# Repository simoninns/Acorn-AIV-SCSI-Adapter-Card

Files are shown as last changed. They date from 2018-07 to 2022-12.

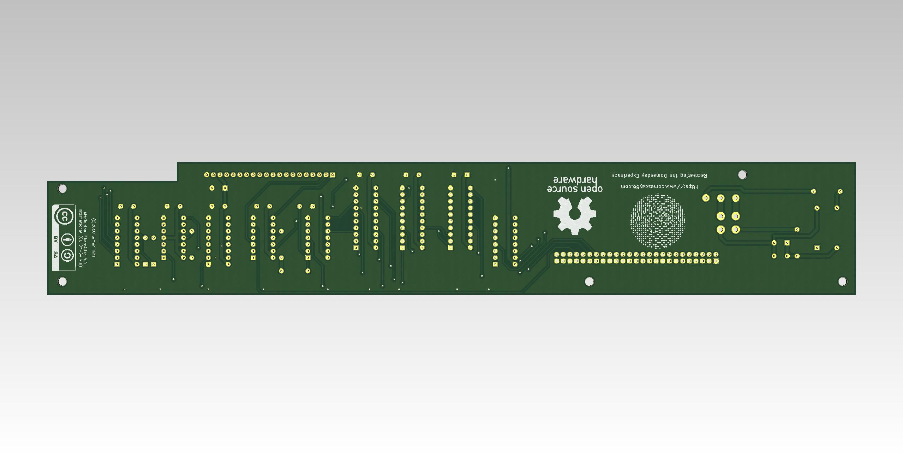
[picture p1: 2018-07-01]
Acorn AIV SCSI Adapter - Bottom.jpg

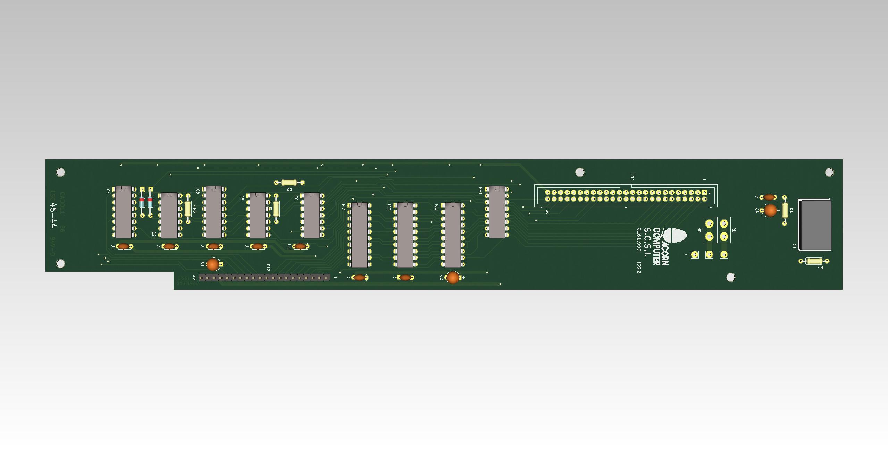
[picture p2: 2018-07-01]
Acorn AIV SCSI Adapter - Top.jpg

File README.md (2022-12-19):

# Acorn-AIV-SCSI-Adapter-Card
A reproduction of the original Acorn AIV SCSI Adapter Card in KiCAD (as used in the BBC Domesday System)

For more information please see the [project wiki pages](https://github.com/simoninns/Acorn-AIV-SCSI-Adapter-Card/wiki)

## Synopsis

This card is designed as a drop-in replacement for the original Acorn card in the BBC Master Microcomputer and allows connection of SCSI devices (such as the Philips VP415 Domesday LaserDisc player).

The layout and routing of the board is based on the original and the board is therefore designed to use the same components.

## Motivation

The Acorn AIV SCSI board is difficult to source and commands a considerable sum on sites such as Ebay.  Using this project you are free to create your own boards for far less cost.  The design and schematics also act as a precise reference to the original design.  The original schematics are available on the web, however they are incorrect.  By recreating the board and following the original routing, the schematics included in this project are verified as correct.

## Author

The Acorn AIV SCSI Adapter Card issue 2 was designed by Simon Inns.

## License

This project is released under a Creative Commons Attribution-ShareAlike 4.0 International (CC BY-SA 4.0) licence.

You are free to:

Share — copy and redistribute the material in any medium or format
Adapt — remix, transform, and build upon the material
for any purpose, even commercially.

This license is acceptable for Free Cultural Works.

The licensor cannot revoke these freedoms as long as you follow the license terms.

Under the following terms:

Attribution — You must give appropriate credit, provide a link to the license,
and indicate if changes were made. You may do so in any reasonable manner, but
not in any way that suggests the licensor endorses you or your use.

ShareAlike — If you remix, transform, or build upon the material, you must
distribute your contributions under the same license as the original.

No additional restrictions — You may not apply legal terms or technological
measures that legally restrict others from doing anything the license permits.

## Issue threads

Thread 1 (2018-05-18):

Mounting holes too small

simoninns, 2018-05-18:
The mounting holes in the current board revision are 2mm in diameter.  The mounting holes should be 3mm.

simoninns, 2018-05-27:
Fixed in latest commit - Mounting holes now M3

Closed 2018-05-27.

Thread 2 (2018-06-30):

Mounting holes not correctly lined up

simoninns, 2018-06-30:
The top mounting holes are a little out (<1mm), but the bottom mounting holes are 2mm out.

The holes need to be checked for alignment between the holes and also with the board in place to make sure the board isn't offset

simoninns, 2018-07-01:
Fixed in commit 3297891

Closed 2018-07-01.

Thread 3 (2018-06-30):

No 16Mhz clock

simoninns, 2018-06-30:
The board doesn't seem to be generating the 16MHz clock signal correctly.  This needs to be checked.

simoninns, 2018-07-01:
This seems to be due to incorrect part selection.  The pin out and routing of the board verifies ok, but the selected component does not produce the required 5V TTL clock output

simoninns, 2018-07-01:
This was due to an incorrect resistor value on the test board.  Clock circuit now verified ok in commit 3297891

Closed 2018-07-01.

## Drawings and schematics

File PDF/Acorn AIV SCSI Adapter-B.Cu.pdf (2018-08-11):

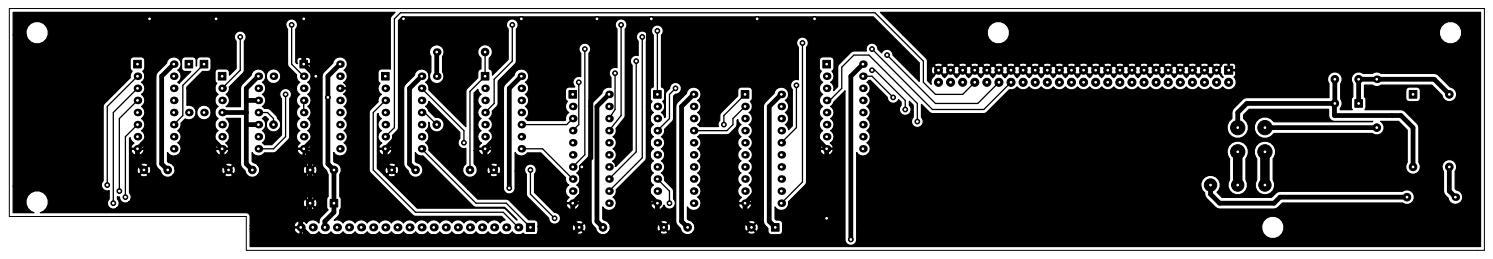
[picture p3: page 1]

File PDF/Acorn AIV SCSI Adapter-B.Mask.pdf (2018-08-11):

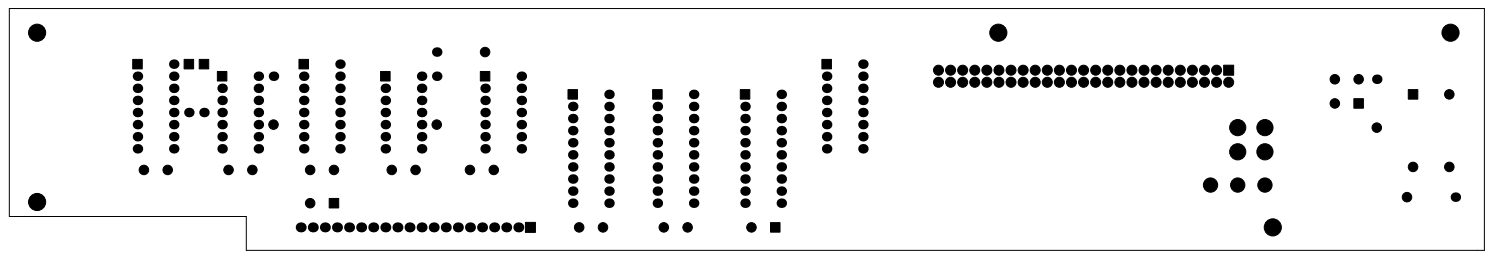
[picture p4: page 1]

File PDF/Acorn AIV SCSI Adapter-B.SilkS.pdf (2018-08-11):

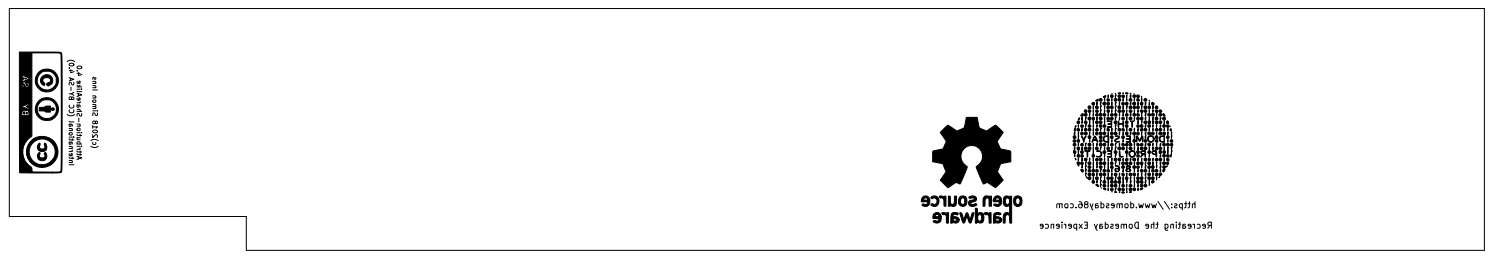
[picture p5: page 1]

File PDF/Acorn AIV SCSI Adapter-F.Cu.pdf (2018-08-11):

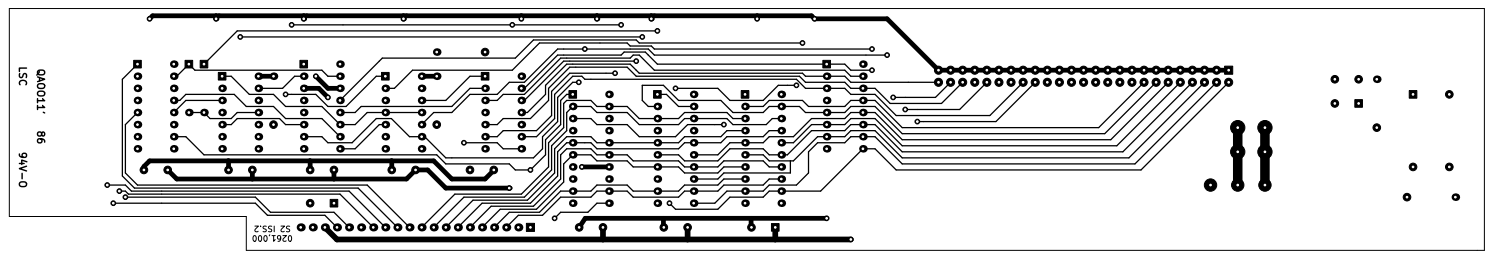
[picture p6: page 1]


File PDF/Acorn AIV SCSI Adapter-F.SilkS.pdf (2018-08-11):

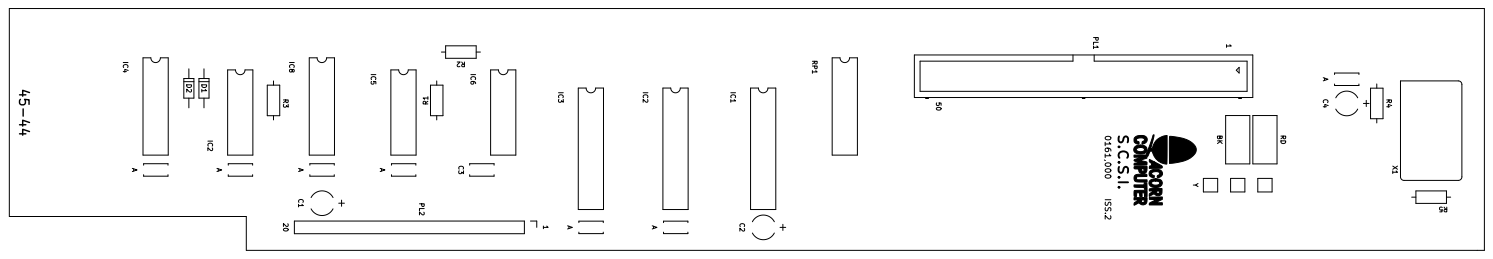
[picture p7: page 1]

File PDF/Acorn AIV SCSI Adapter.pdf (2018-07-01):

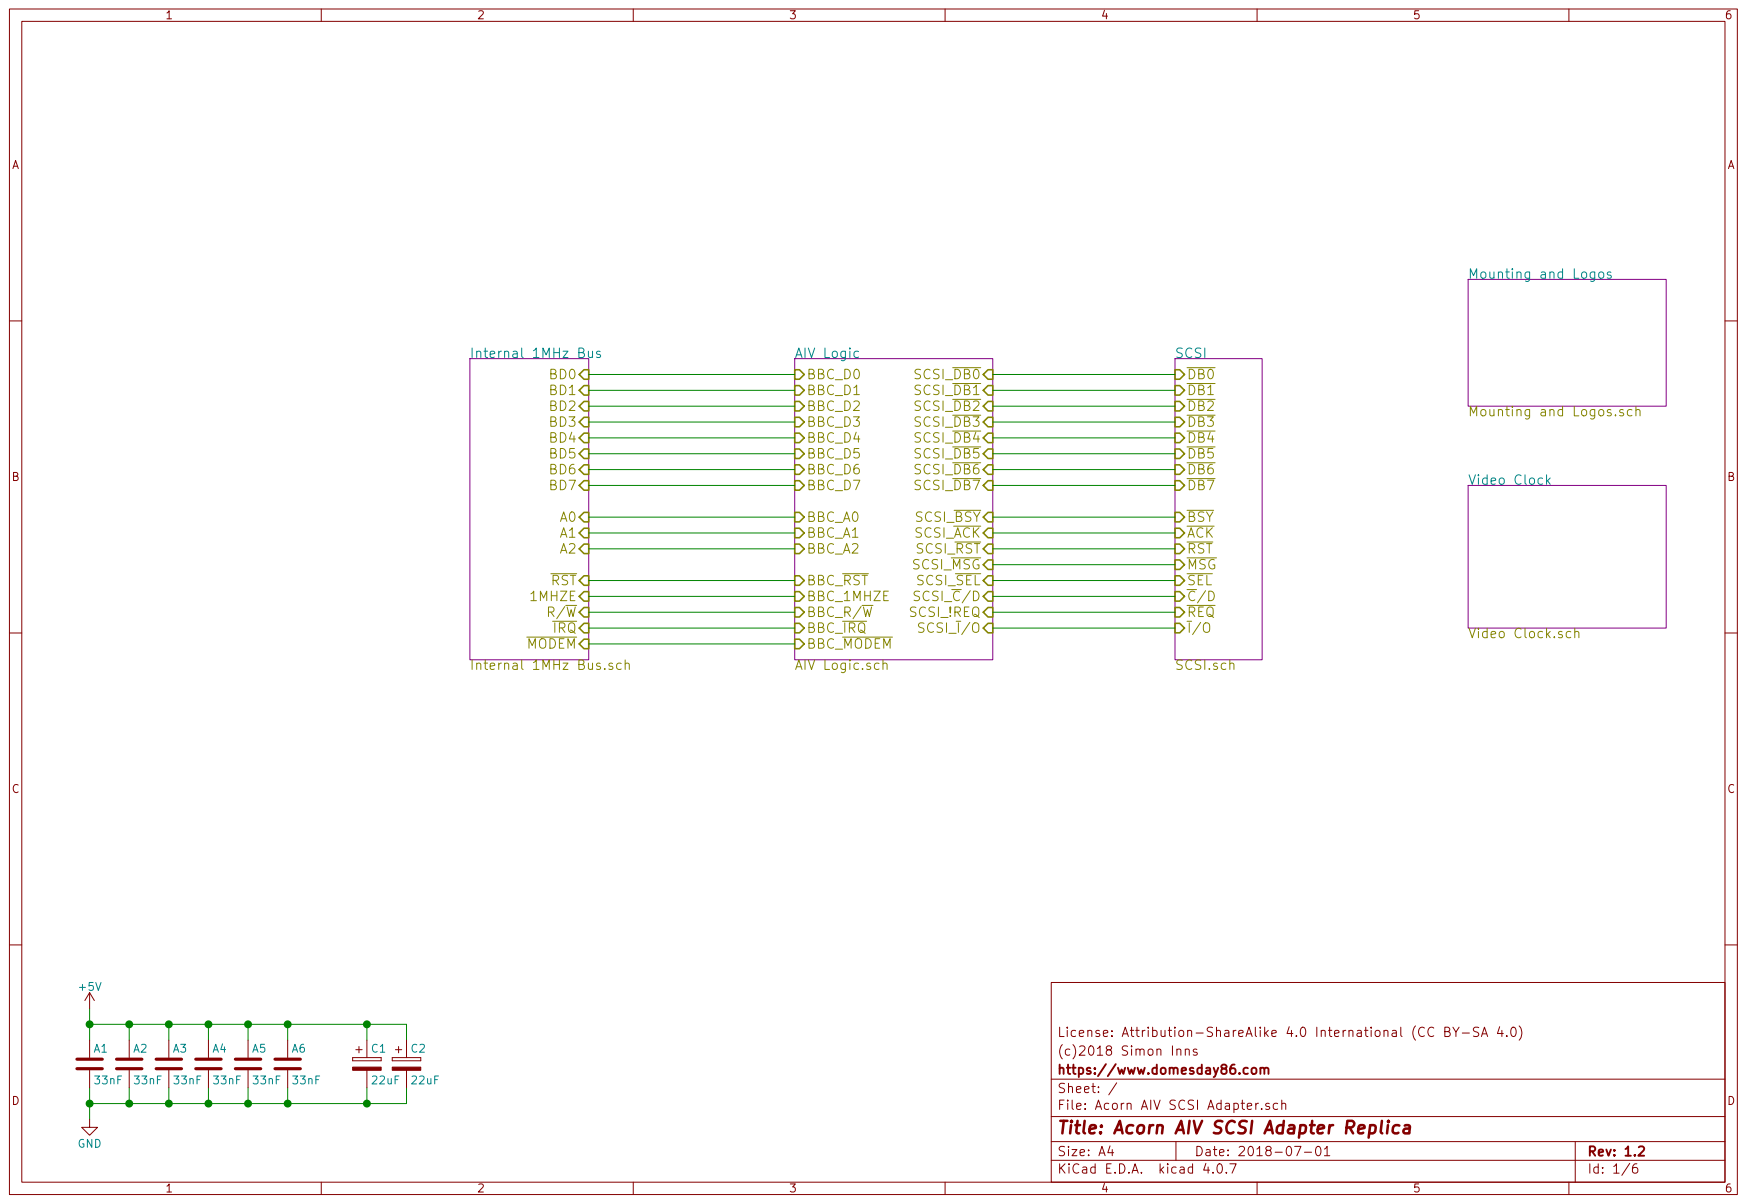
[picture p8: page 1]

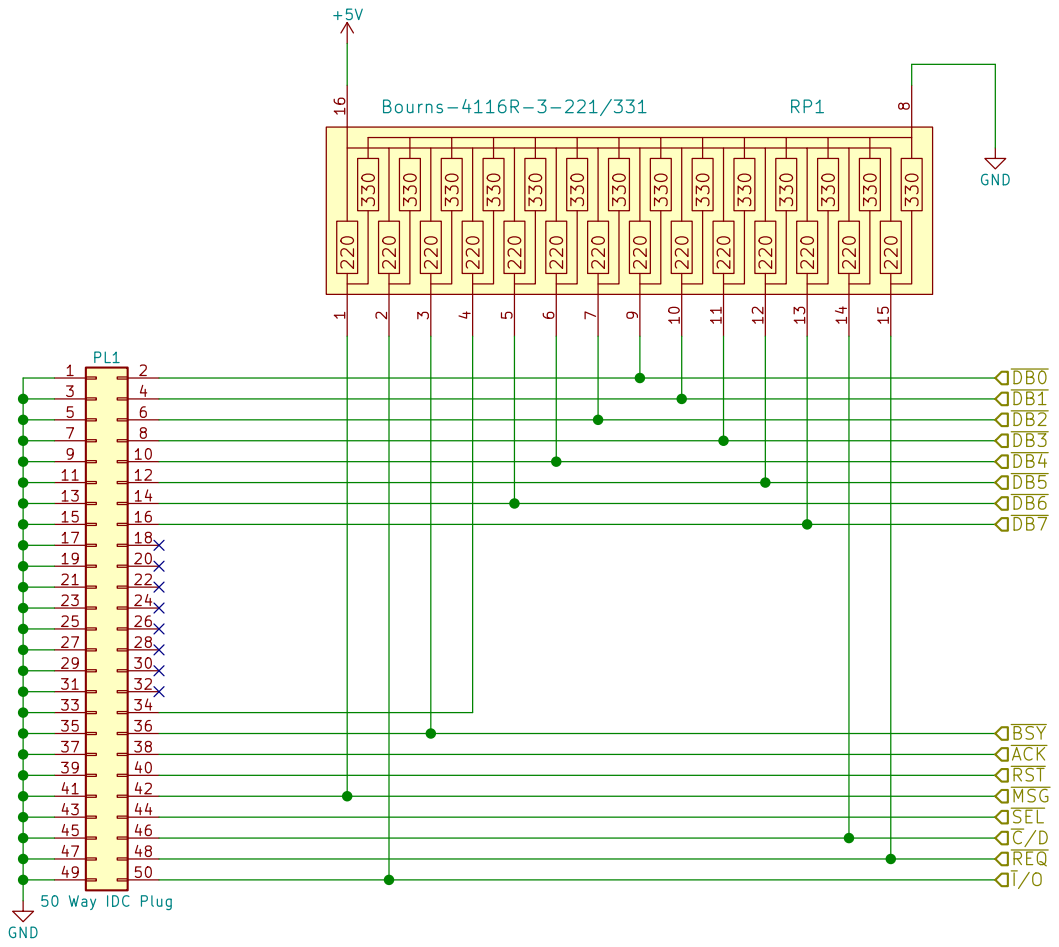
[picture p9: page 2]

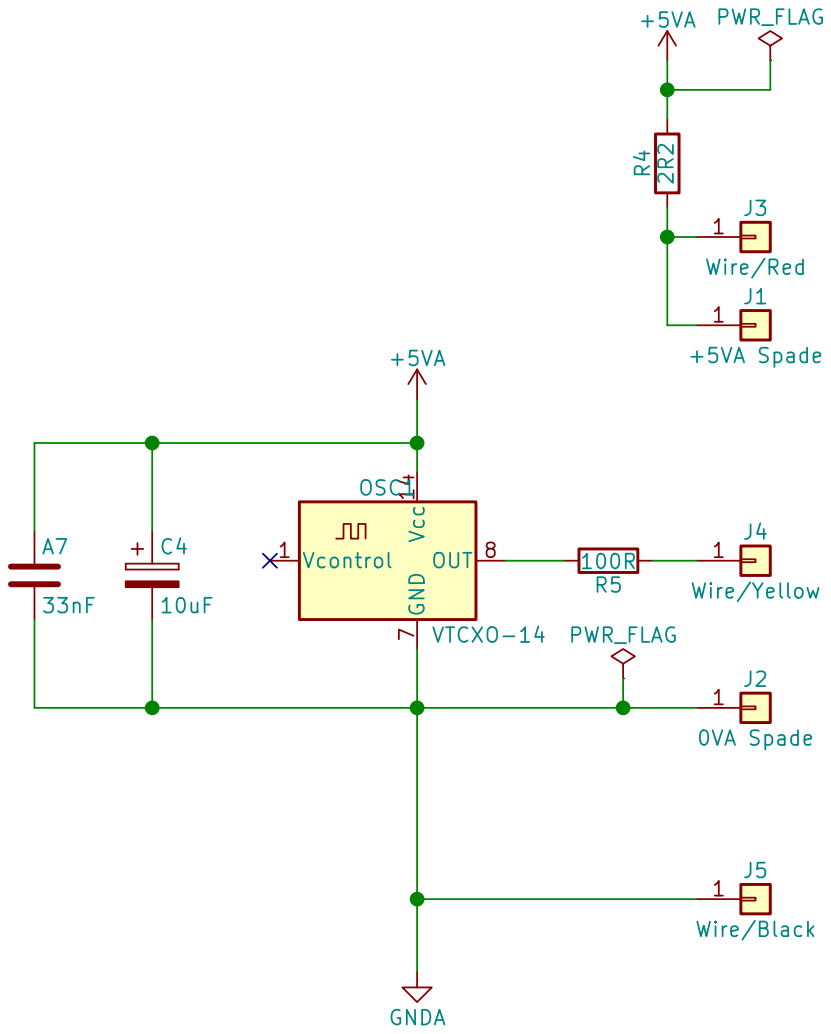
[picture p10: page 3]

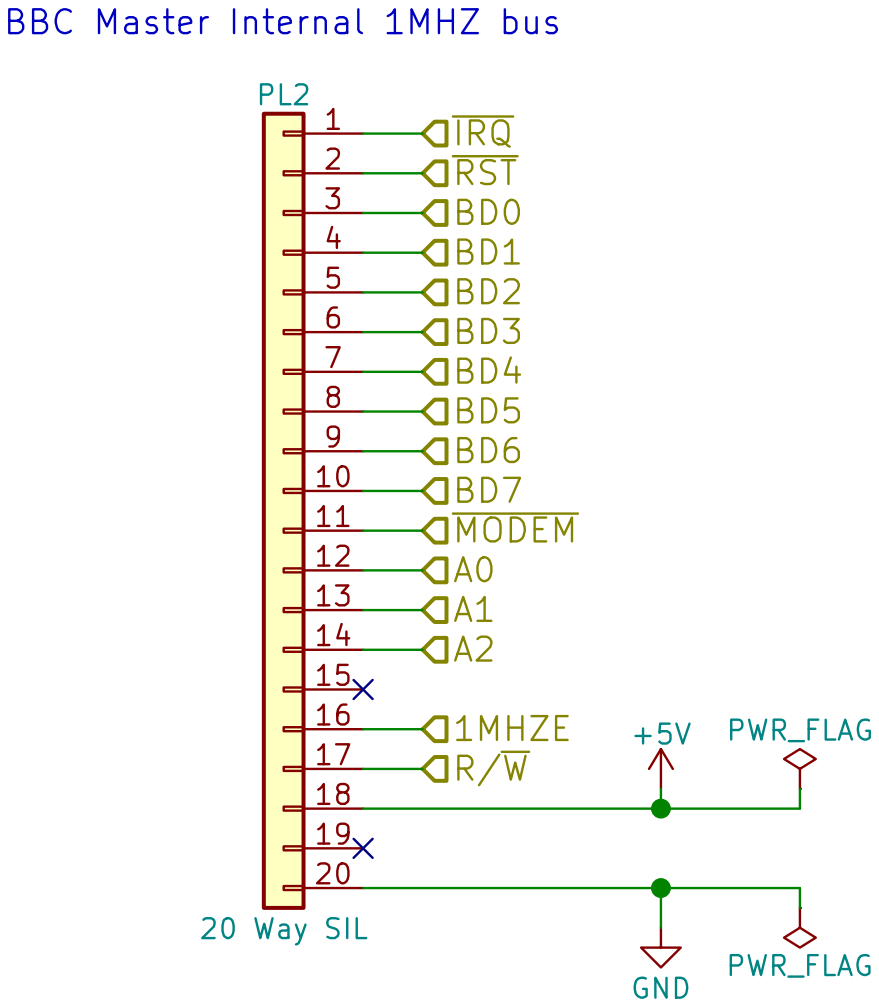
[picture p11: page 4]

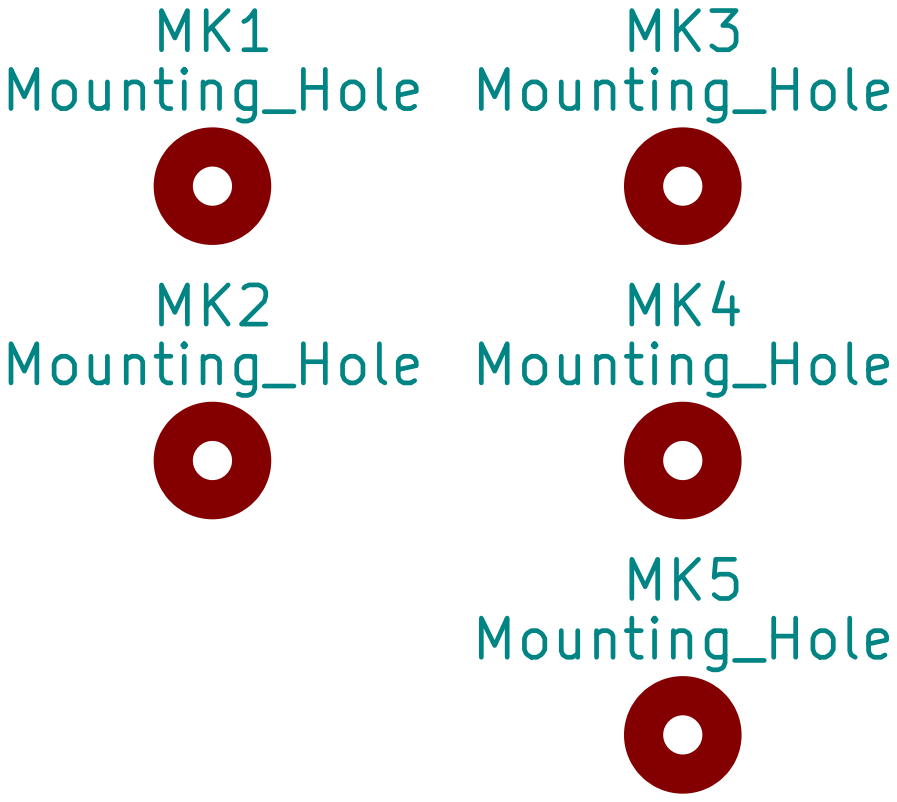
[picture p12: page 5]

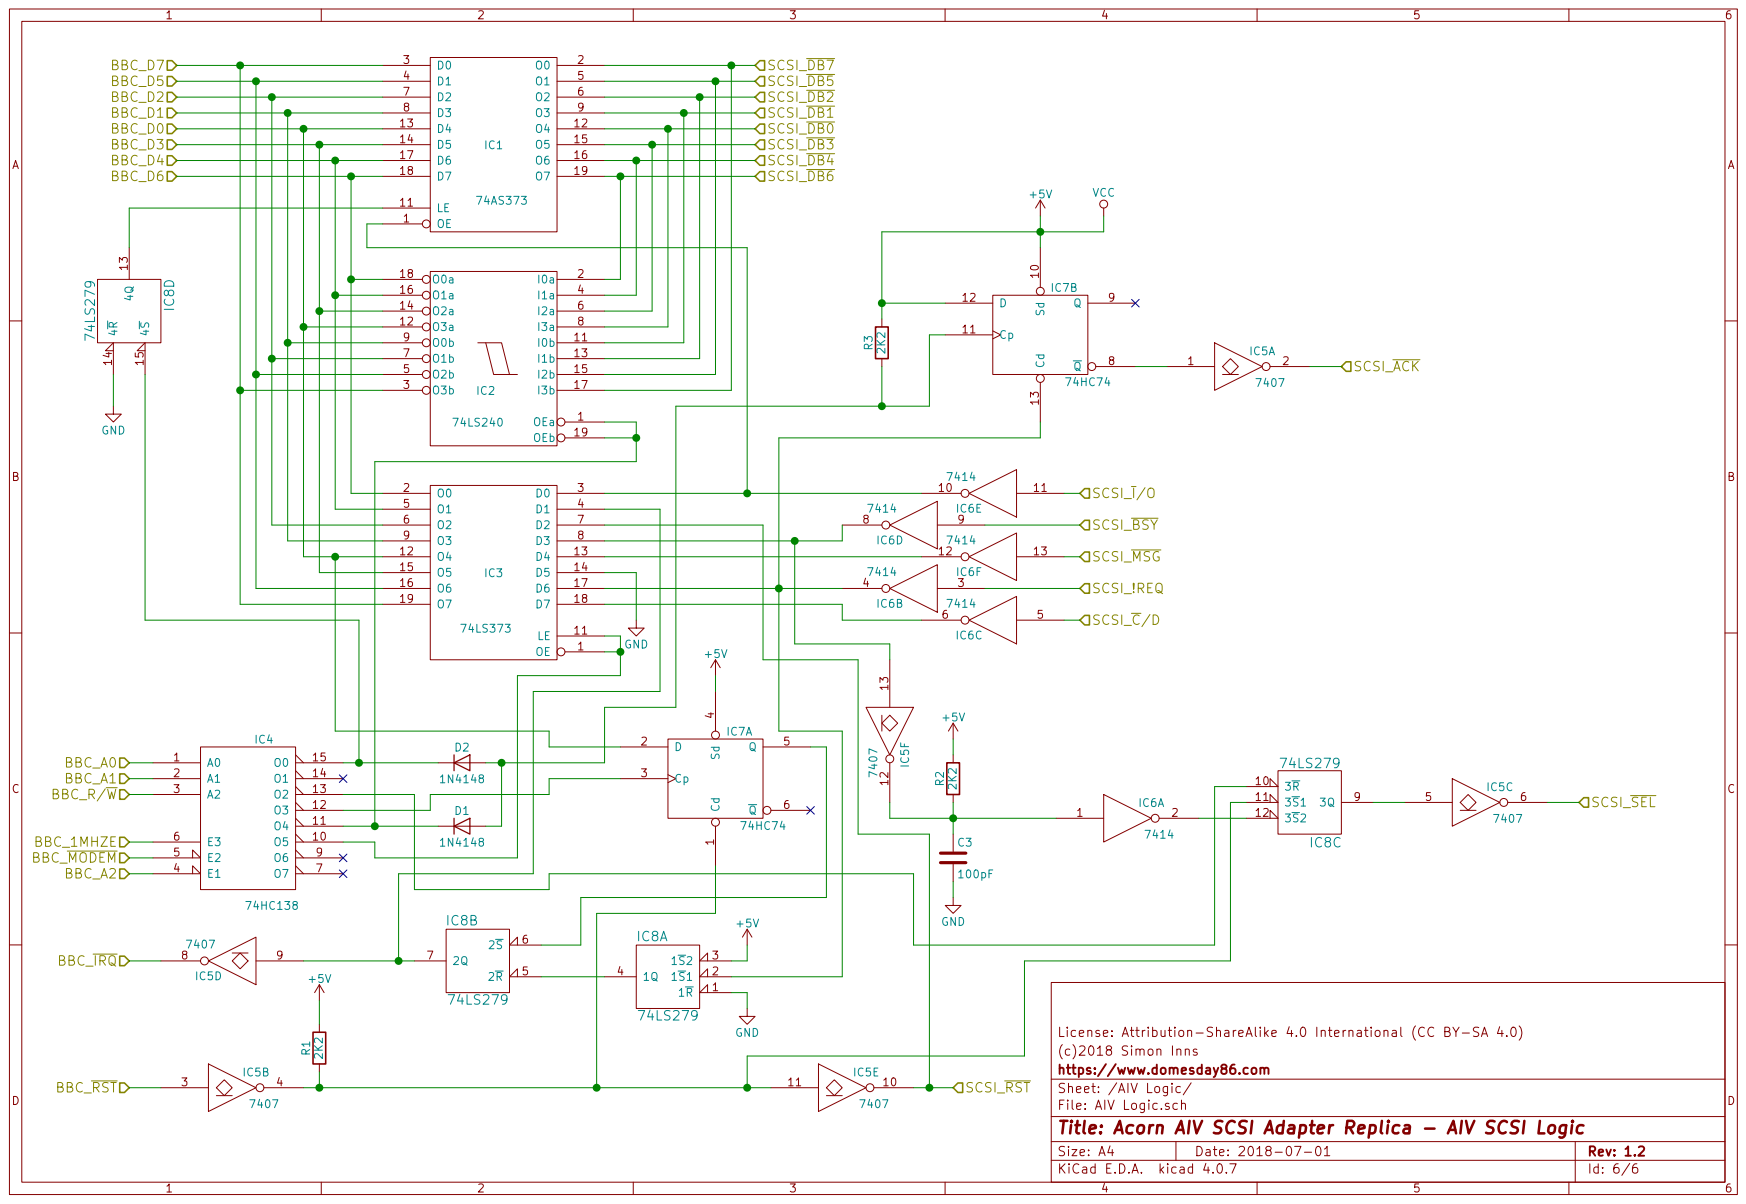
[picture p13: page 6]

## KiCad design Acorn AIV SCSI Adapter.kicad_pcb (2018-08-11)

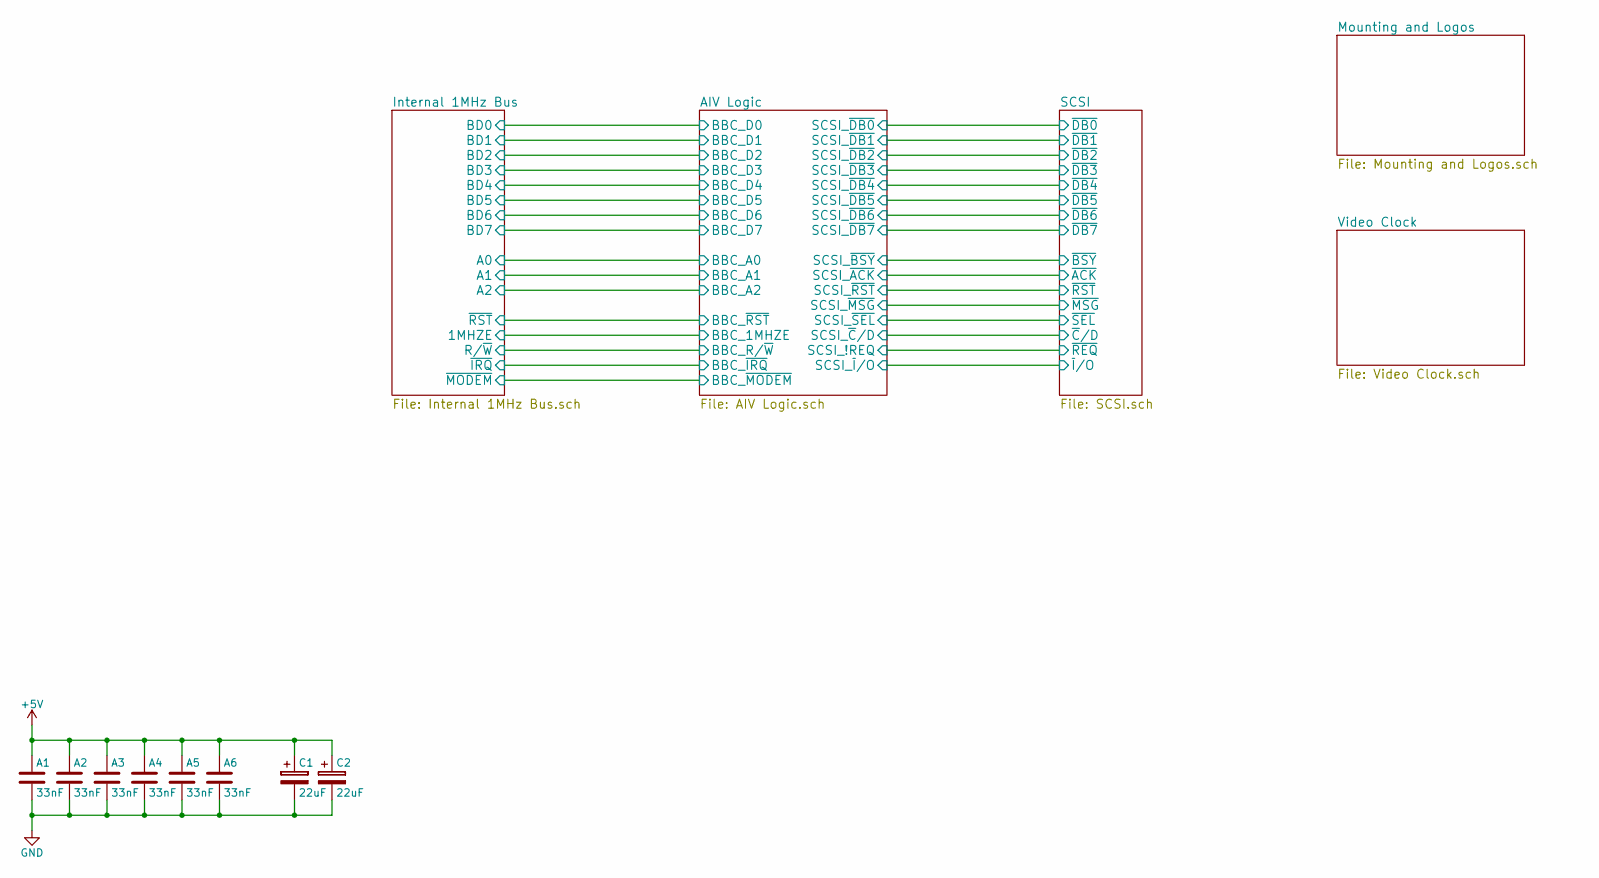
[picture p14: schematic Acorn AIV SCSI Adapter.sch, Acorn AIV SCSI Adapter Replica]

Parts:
A1, A2, A3, A4, A5, A6: 33nF; C_Disc_D5.0mm_W2.5mm_P5.00mm
C1, C2: 22uF; CP_Radial_Tantal_D5.0mm_P5.00mm

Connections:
+5V: A1.1, A2.1, A3.1, A4.1, A5.1, A6.1, C1.1, C2.1; also elsewhere on the board
GND: A1.2, A2.2, A3.2, A4.2, A5.2, A6.2, C1.2, C2.2; also elsewhere on the board

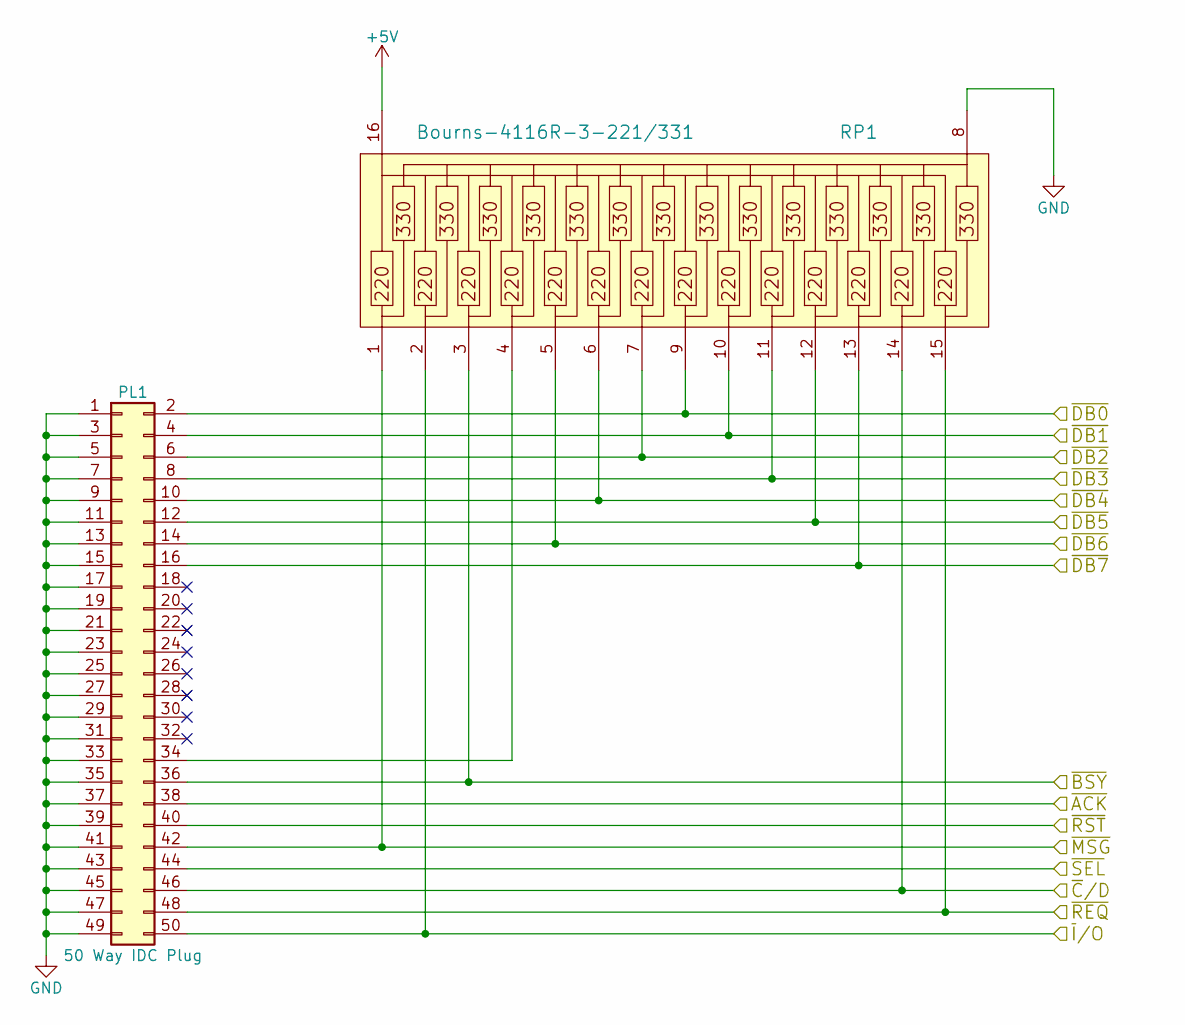
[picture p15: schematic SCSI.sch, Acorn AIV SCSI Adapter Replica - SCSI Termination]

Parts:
PL1: 50 Way IDC Plug; Multicomp_MC9A12-5034_2x25x2.54mm_Straight
RP1: Bourns-4116R-3-221/331; DIP-16_W7.62mm

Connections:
+5V: RP1.16; also elsewhere on the board
/AIV Logic/SCSI_!REQ: PL1.48, RP1.15; also elsewhere on the board
/AIV Logic/SCSI_~ACK: PL1.38; also elsewhere on the board
/AIV Logic/SCSI_~BSY: PL1.36, RP1.3; also elsewhere on the board
/AIV Logic/SCSI_~C~/D: PL1.46, RP1.14; also elsewhere on the board
/AIV Logic/SCSI_~DB0: PL1.2, RP1.9; also elsewhere on the board
/AIV Logic/SCSI_~DB1: PL1.4, RP1.10; also elsewhere on the board
/AIV Logic/SCSI_~DB2: PL1.6, RP1.7; also elsewhere on the board
/AIV Logic/SCSI_~DB3: PL1.8, RP1.11; also elsewhere on the board
/AIV Logic/SCSI_~DB4: PL1.10, RP1.6; also elsewhere on the board
/AIV Logic/SCSI_~DB5: PL1.12, RP1.12; also elsewhere on the board
/AIV Logic/SCSI_~DB6: PL1.14, RP1.5; also elsewhere on the board
/AIV Logic/SCSI_~DB7: PL1.16, RP1.13; also elsewhere on the board
/AIV Logic/SCSI_~I~/O: PL1.50, RP1.2; also elsewhere on the board
/AIV Logic/SCSI_~MSG: PL1.42, RP1.1; also elsewhere on the board
/AIV Logic/SCSI_~RST: PL1.40; also elsewhere on the board
/AIV Logic/SCSI_~SEL: PL1.44; also elsewhere on the board
GND: PL1.1, PL1.3, PL1.5, PL1.7, PL1.9, PL1.11, PL1.13, PL1.15, PL1.17, PL1.19, PL1.21, PL1.23, PL1.25, PL1.27, PL1.29, PL1.31, PL1.33, PL1.35, PL1.37, PL1.39, PL1.41, PL1.43, PL1.45, PL1.47, PL1.49, RP1.8; also elsewhere on the board
unnamed: PL1.34, RP1.4

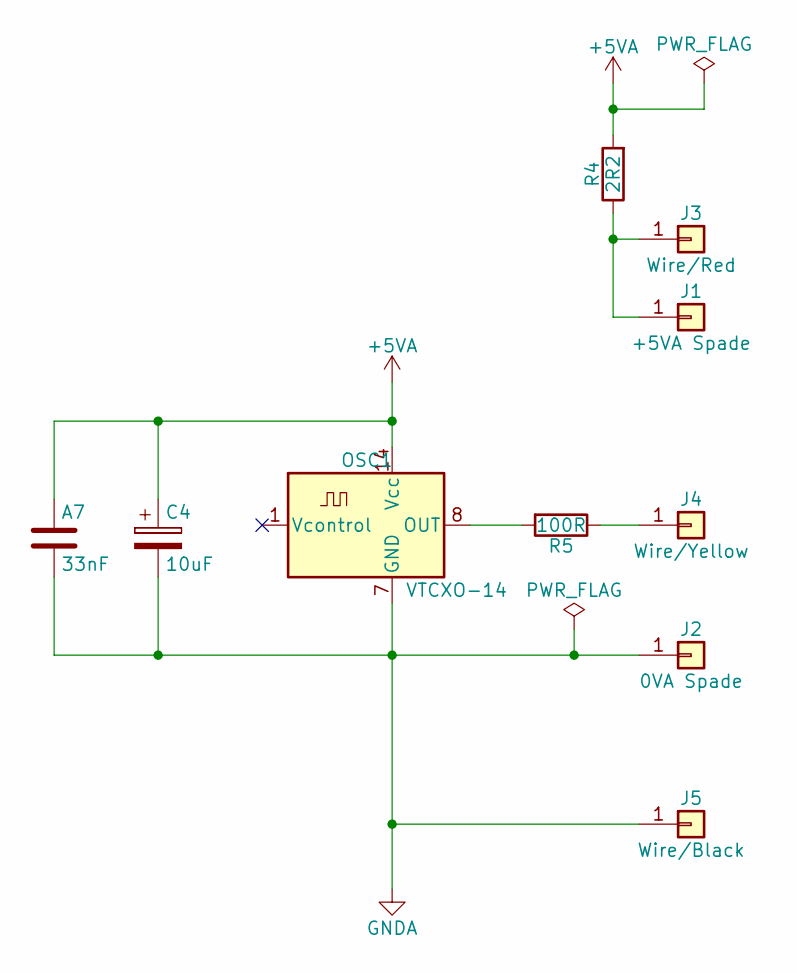
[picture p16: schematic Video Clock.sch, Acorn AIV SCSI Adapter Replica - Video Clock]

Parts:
A7: 33nF; C_Disc_D5.0mm_W2.5mm_P5.00mm
C4: 10uF; CP_Radial_Tantal_D5.0mm_P5.00mm
J1: +5VA Spade; PCB_Blade_Terminal_6.3mm
J2: 0VA Spade; PCB_Blade_Terminal_6.3mm
J3: Wire/Red; Pin_d1.4mm_L8.5mm_W2.8mm_FlatFork
J4: Wire/Yellow; Pin_d1.4mm_L8.5mm_W2.8mm_FlatFork
J5: Wire/Black; Pin_d1.4mm_L8.5mm_W2.8mm_FlatFork
OSC1: VTCXO-14; Oscillator_DIP-14
R4: 2R2; R_Axial_DIN0207_L6.3mm_D2.5mm_P10.16mm_Horizontal
R5: 100R; R_Axial_DIN0207_L6.3mm_D2.5mm_P10.16mm_Horizontal

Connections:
+5VA: A7.1, C4.1, OSC1.14 (Vcc), R4.2
GNDA: A7.2, C4.2, J2.1, J5.1, OSC1.7 (GND)
unnamed: J1.1, J3.1, R4.1
unnamed: J4.1, R5.1
unnamed: OSC1.8 (OUT), R5.2

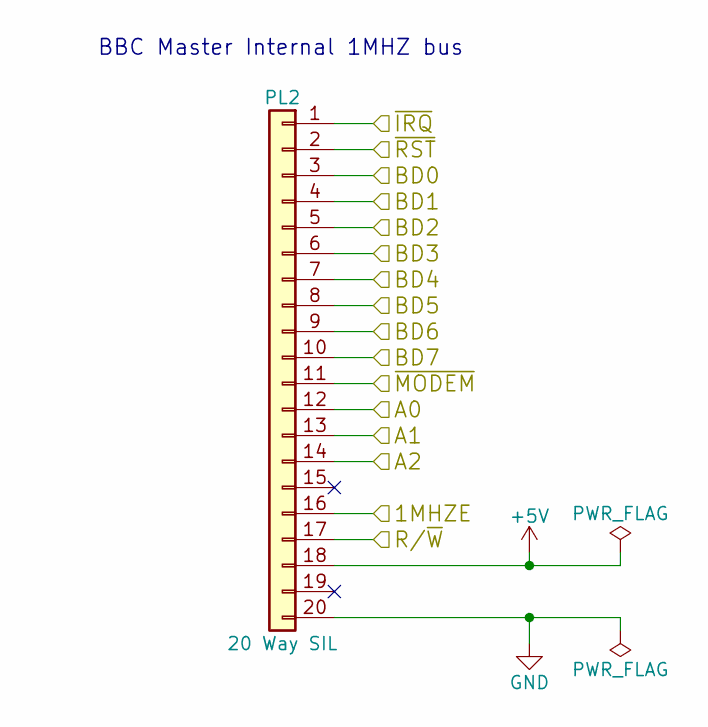
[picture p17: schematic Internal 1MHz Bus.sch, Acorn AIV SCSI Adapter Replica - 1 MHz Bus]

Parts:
PL2: 20 Way SIL; Pin_Header_Straight_1x20_Pitch2.54mm

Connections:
+5V: PL2.18; also elsewhere on the board
/AIV Logic/BBC_D0: PL2.3; also elsewhere on the board
/AIV Logic/BBC_D1: PL2.4; also elsewhere on the board
/AIV Logic/BBC_D2: PL2.5; also elsewhere on the board
/AIV Logic/BBC_D3: PL2.6; also elsewhere on the board
/AIV Logic/BBC_D4: PL2.7; also elsewhere on the board
/AIV Logic/BBC_D5: PL2.8; also elsewhere on the board
/AIV Logic/BBC_D6: PL2.9; also elsewhere on the board
/AIV Logic/BBC_D7: PL2.10; also elsewhere on the board
/AIV Logic/BBC_R/~W: PL2.17; also elsewhere on the board
/AIV Logic/BBC_~IRQ: PL2.1; also elsewhere on the board
/AIV Logic/BBC_~MODEM: PL2.11; also elsewhere on the board
/AIV Logic/BBC_~RST: PL2.2; also elsewhere on the board
/Internal 1MHz Bus/1MHZE: PL2.16; also elsewhere on the board
/Internal 1MHz Bus/A0: PL2.12; also elsewhere on the board
/Internal 1MHz Bus/A1: PL2.13; also elsewhere on the board
/Internal 1MHz Bus/A2: PL2.14; also elsewhere on the board
GND: PL2.20; also elsewhere on the board

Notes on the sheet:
BBC Master Internal 1MHZ bus

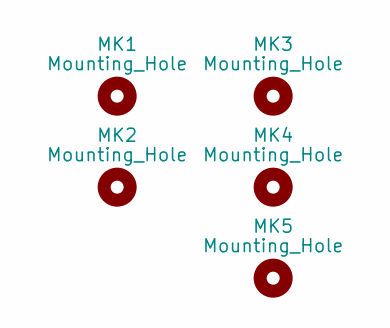
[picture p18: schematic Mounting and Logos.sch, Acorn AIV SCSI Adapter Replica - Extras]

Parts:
MK1, MK2, MK3, MK4, MK5: Mounting_Hole; MountingHole_3.2mm_M3

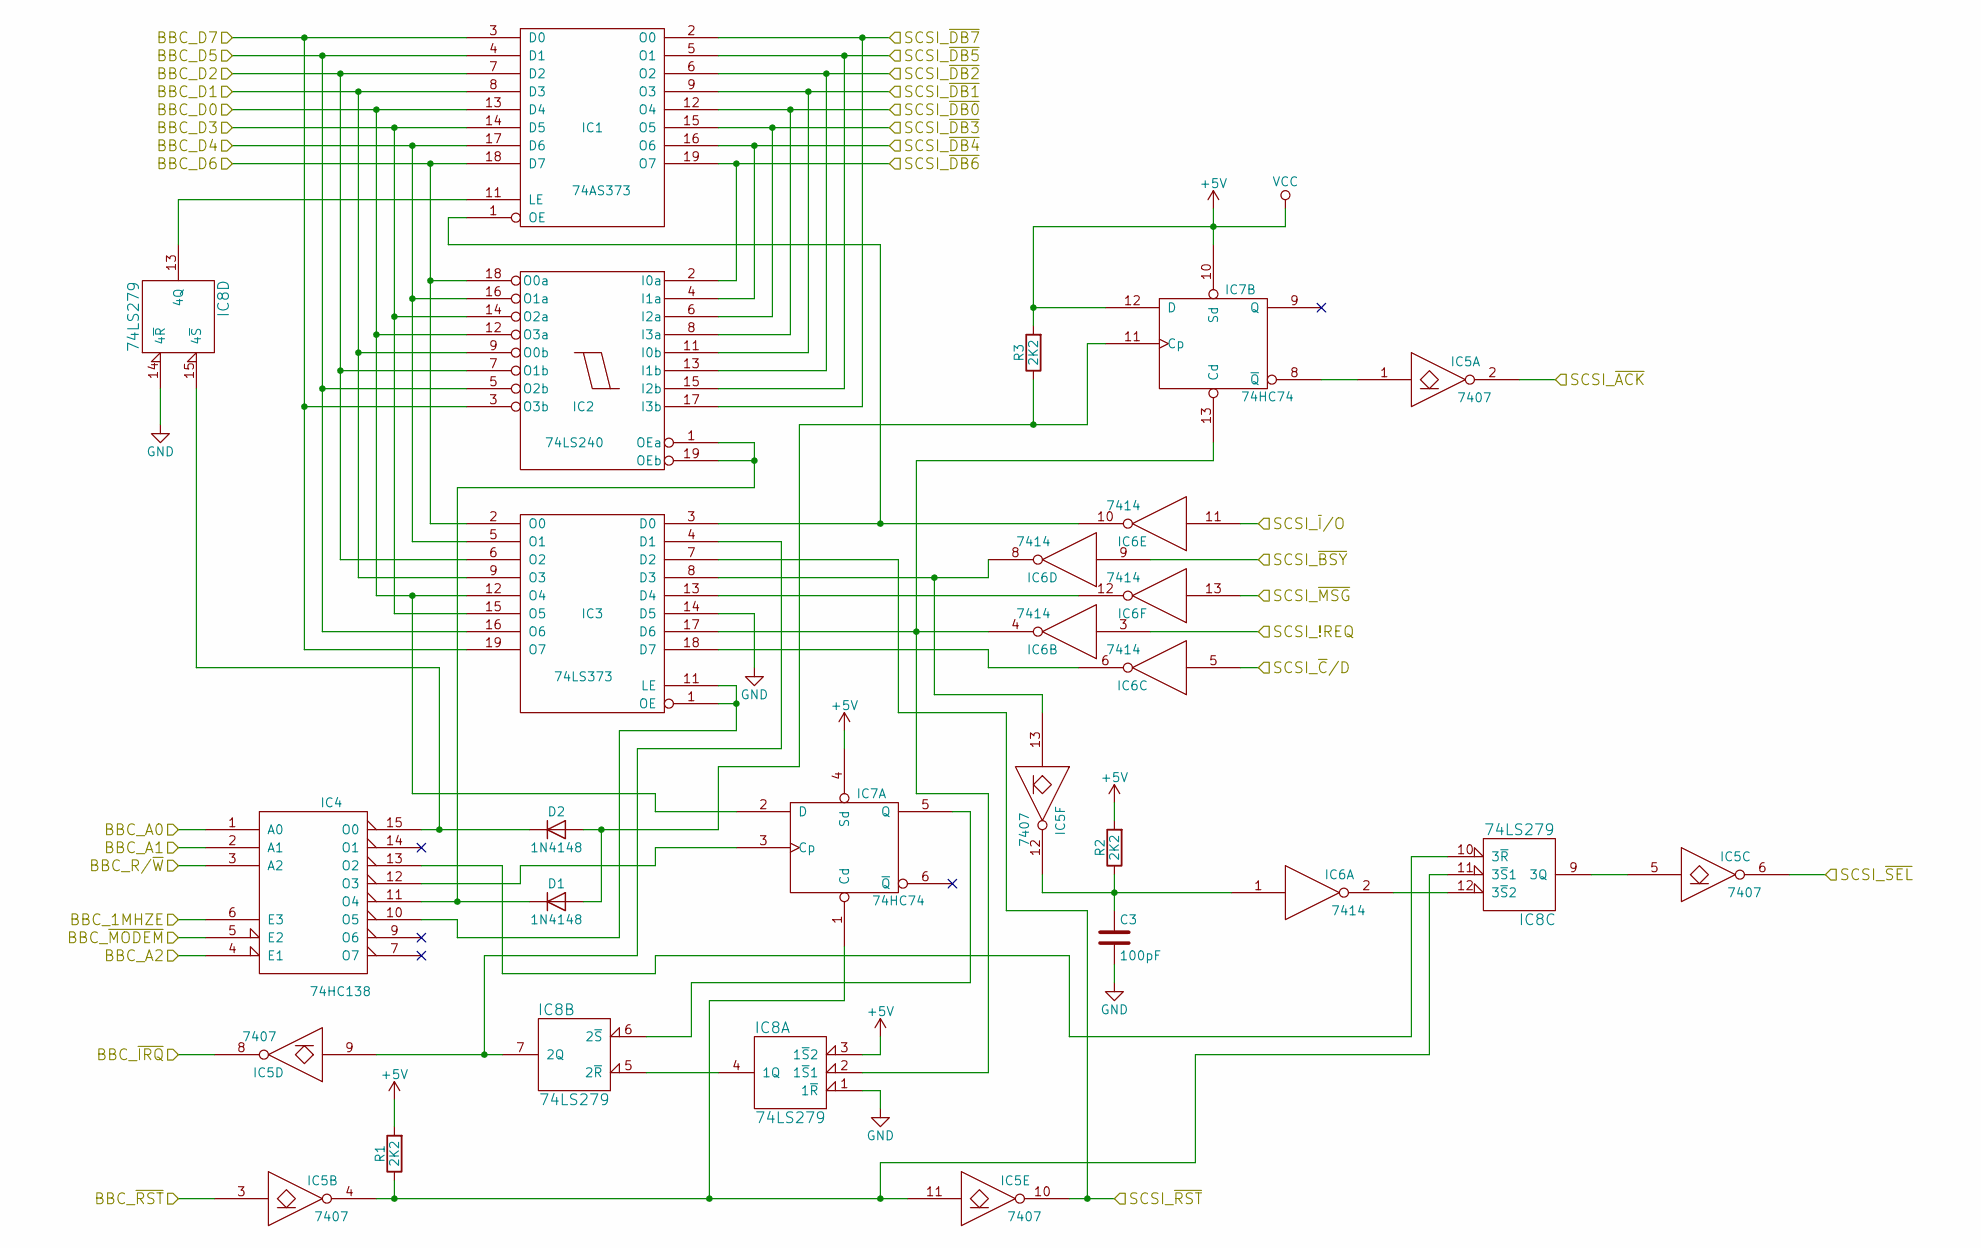
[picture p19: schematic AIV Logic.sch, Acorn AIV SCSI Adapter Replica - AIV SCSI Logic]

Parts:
C3: 100pF; C_Disc_D5.0mm_W2.5mm_P5.00mm
D1, D2: 1N4148; D_DO-35_SOD27_P10.16mm_Horizontal
IC1: 74AS373; DIP-20_W7.62mm
IC2: 74LS240; DIP-20_W7.62mm
IC3: 74LS373; DIP-20_W7.62mm
IC4: 74HC138; DIP-16_W7.62mm
IC5: 7407; DIP-14_W7.62mm
IC6: 7414; DIP-14_W7.62mm
IC7: 74HC74; DIP-14_W7.62mm
IC8: 74LS279; DIP-16_W7.62mm
R1, R2, R3: 2K2; R_Axial_DIN0207_L6.3mm_D2.5mm_P10.16mm_Horizontal

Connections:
+5V: IC1.20 (VCC), IC2.20 (VCC), IC3.20 (VCC), IC4.16 (VCC), IC5.14 (VCC), IC6.14 (VCC), IC7.4 (Sd), IC7.10 (Sd), IC7.12 (D), IC7.14 (VCC), IC8.3 (1~S~2), IC8.16 (Vcc), R1.2, R2.2, R3.2; also elsewhere on the board
/AIV Logic/BBC_D0: IC1.13 (D4), IC2.12 (O3a), IC3.12 (O4), IC7.2 (D); also elsewhere on the board
/AIV Logic/BBC_D1: IC1.8 (D3), IC2.9 (O0b), IC3.9 (O3); also elsewhere on the board
/AIV Logic/BBC_D2: IC1.7 (D2), IC2.7 (O1b), IC3.6 (O2); also elsewhere on the board
/AIV Logic/BBC_D3: IC1.14 (D5), IC2.14 (O2a), IC3.15 (O5); also elsewhere on the board
/AIV Logic/BBC_D4: IC1.17 (D6), IC2.16 (O1a), IC3.5 (O1); also elsewhere on the board
/AIV Logic/BBC_D5: IC1.4 (D1), IC2.5 (O2b), IC3.16 (O6); also elsewhere on the board
/AIV Logic/BBC_D6: IC1.18 (D7), IC2.18 (O0a), IC3.2 (O0); also elsewhere on the board
/AIV Logic/BBC_D7: IC1.3 (D0), IC2.3 (O3b), IC3.19 (O7); also elsewhere on the board
/AIV Logic/BBC_R/~W: IC4.3 (A2); also elsewhere on the board
/AIV Logic/BBC_~IRQ: IC5.8; also elsewhere on the board
/AIV Logic/BBC_~MODEM: IC4.5 (E2); also elsewhere on the board
/AIV Logic/BBC_~RST: IC5.3; also elsewhere on the board
/AIV Logic/SCSI_!REQ: IC6.3; also elsewhere on the board
/AIV Logic/SCSI_~ACK: IC5.2; also elsewhere on the board
/AIV Logic/SCSI_~BSY: IC6.9; also elsewhere on the board
/AIV Logic/SCSI_~C~/D: IC6.5; also elsewhere on the board
/AIV Logic/SCSI_~DB0: IC1.12 (O4), IC2.8 (I3a); also elsewhere on the board
/AIV Logic/SCSI_~DB1: IC1.9 (O3), IC2.11 (I0b); also elsewhere on the board
/AIV Logic/SCSI_~DB2: IC1.6 (O2), IC2.13 (I1b); also elsewhere on the board
/AIV Logic/SCSI_~DB3: IC1.15 (O5), IC2.6 (I2a); also elsewhere on the board
/AIV Logic/SCSI_~DB4: IC1.16 (O6), IC2.4 (I1a); also elsewhere on the board
/AIV Logic/SCSI_~DB5: IC1.5 (O1), IC2.15 (I2b); also elsewhere on the board
/AIV Logic/SCSI_~DB6: IC1.19 (O7), IC2.2 (I0a); also elsewhere on the board
/AIV Logic/SCSI_~DB7: IC1.2 (O0), IC2.17 (I3b); also elsewhere on the board
/AIV Logic/SCSI_~I~/O: IC6.11; also elsewhere on the board
/AIV Logic/SCSI_~MSG: IC6.13; also elsewhere on the board
/AIV Logic/SCSI_~RST: IC3.7 (D2), IC5.10; also elsewhere on the board
/AIV Logic/SCSI_~SEL: IC5.6; also elsewhere on the board
/Internal 1MHz Bus/1MHZE: IC4.6 (E3); also elsewhere on the board
/Internal 1MHz Bus/A0: IC4.1 (A0); also elsewhere on the board
/Internal 1MHz Bus/A1: IC4.2 (A1); also elsewhere on the board
/Internal 1MHz Bus/A2: IC4.4 (E1); also elsewhere on the board
GND: C3.2, IC1.10 (GND), IC2.10 (GND), IC3.10 (GND), IC3.14 (D5), IC4.8 (GND), IC5.7 (GND), IC6.7 (GND), IC7.7 (GND), IC8.1 (1~R), IC8.8 (GND), IC8.14 (4~R); also elsewhere on the board
unnamed: C3.1, IC5.12, IC6.1, R2.1
unnamed: D1.1 (K), IC2.1 (OEa), IC2.19 (OEb), IC4.11 (O4)
unnamed: D1.2 (A), D2.2 (A), IC7.11 (Cp), R3.1
unnamed: D2.1 (K), IC4.15 (O0), IC8.15 (4~S)
unnamed: IC1.1 (OE), IC3.3 (D0), IC6.10
unnamed: IC1.11 (LE), IC8.13 (4Q)
unnamed: IC3.1 (OE), IC3.11 (LE), IC4.10 (O5)
unnamed: IC3.4 (D1), IC5.9, IC8.7 (2Q)
unnamed: IC3.8 (D3), IC5.13, IC6.8
unnamed: IC3.13 (D4), IC6.12
unnamed: IC3.17 (D6), IC6.4, IC7.13 (Cd), IC8.2 (1~S~1)
unnamed: IC3.18 (D7), IC6.6
unnamed: IC4.12 (O3), IC7.3 (Cp)
unnamed: IC4.13 (O2), IC8.10 (3~R)
unnamed: IC5.1, IC7.8 (~Q)
unnamed: IC5.5, IC8.9 (3Q)
unnamed: IC5.4, IC5.11, IC7.1 (Cd), IC8.11 (3~S~1), R1.1
unnamed: IC6.2, IC8.12 (3~S~2)
unnamed: IC7.5 (Q), IC8.6 (2~S)
unnamed: IC8.4 (1Q), IC8.5 (2~R)

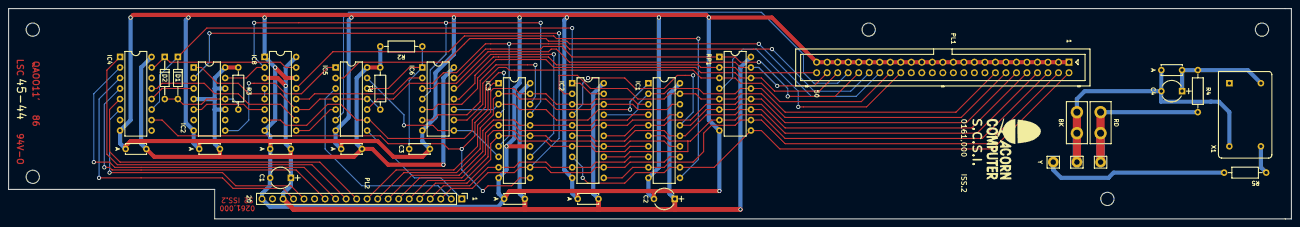
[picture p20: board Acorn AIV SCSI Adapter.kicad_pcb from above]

Board: 2 copper layers, 309.9 x 50.8 mm, 40 parts (0 on the bottom side), 60 nets.

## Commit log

2018-04-29 Initial release of project to Github
    [AIV Logic.sch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]
2018-05-04 Added back-copper ground plane fill and updated gerbers
    [Acorn AIV SCSI Adapter-B.Cu.gbr, Acorn AIV SCSI Adapter-B.Mask.gbr, Acorn AIV SCSI Adapter-B.SilkS.gbr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]
2018-05-27 FIxed issue #1
    [AIV Logic.sch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]
2018-07-01 Corrected mounting holes and silkscreen
    [AIV Logic.sch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]
2018-08-11 Adjustment to mounting holes for better alignment
    [Acorn AIV SCSI Adapter-B.Cu.gbr, Acorn AIV SCSI Adapter-B.Mask.gbr, Acorn AIV SCSI Adapter-B.SilkS.gbr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]

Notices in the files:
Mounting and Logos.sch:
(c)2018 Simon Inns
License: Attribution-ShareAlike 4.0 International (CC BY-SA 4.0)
